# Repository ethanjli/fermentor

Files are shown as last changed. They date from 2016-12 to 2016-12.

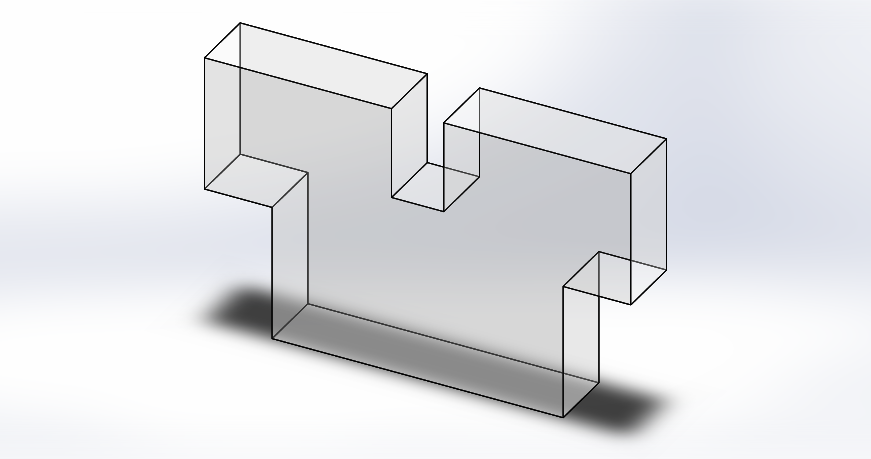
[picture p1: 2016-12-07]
design/mechanical/vessel/Temperature Sensor Mounting Plate.PNG

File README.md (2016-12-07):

# fermentor
fermentor is the codebase for a Raspberry Pi to operate a simple Arduino-driven fermentor and provide a real-time web interface for high-level control of fermentor behavior. This was done by Ethan Li and Jessica Lam for the project extension for BIOE 123 ("Optics and Devices Lab") at Stanford University. This project implements proportional temperature control of a fermentor, along with OD and green absorption sensing to monitor growth of a custom E coli strain that produces purple protein. View a writeup of the project at [ethanjli.github.io/fermentor](//ethanjli.github.io/fermentor).

## Dependencies
The following must be installed to run the web interface:
- [python 2](https://www.python.org/): required by Flask-SocketIO
- [numpy](http://www.numpy.org/): for basic data processing
- [Flask](http://flask.pocoo.org/)
- [Flask-SocketIO](https://github.com/miguelgrinberg/Flask-SocketIO) for real-time communication between a web browser and the server
- [Python-Arduino-Command-API](https://github.com/thearn/Python-Arduino-Command-API) for Arduino interfacing.

The project also uses [jQuery](http://jquery.com) for live page updating and [Google Charts](https://developers.google.com/chart/) for data plotting.

## Issues
Because this project was implemented only over a span of four days, and all of its substantive components were implemented over the course of 48 hours, this project is not good for production use:
- The plot update messages sent over WebSockets are wasteful in terms of data and processor time.
- UI design was not a high priority, given the time constraints.
- The data structures used are not the most suitable ones possible. They are not always initialized/reinitialized properly.
- The project did not undergo exhaustive testing or thorough quality checking.
- Certain routines are underdecomposed.
- Interface and naming are messy.
- Potential race conditions between multiple browser clients are not considered.
- Documentation is lacking in many areas.
- Notably, when the web interface is run on a Raspberry Pi B+ on a 2 A power suppply while powering an Arduino, it tends to brownout. In cases when CPU load is high, the code interfacing to the Arduino tends to read egregiously incorrect temperature values.

## Getting Started
When all dependencies are installed, run `fermenter.py` for basic (non-interactive) control of the fermenter. To expose the web interface, instead run `app.py` with the necessary permissions. For example, to serve the web interface on port 80, you may need to run it through `sudo`.

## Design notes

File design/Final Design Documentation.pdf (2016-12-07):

# Final Design Documentation

## Requirements

The fermentor is to grow E. coli under constant temperature conditions while monitoring the cell color change, the overall density of the cells.

The following requirements were provided by the course instructors, and system specifications were developed to meet them:

1. Sustain a fluid medium of 150 – 200 mL, without leaking
2. Maintain an internal fluid medium temperature appropriate for growing E. coli (37 deg C +/- 1 deg C)
3. Enable controlled medium sampling and material introduction without interrupting operation
4. Provide adequate aeration of fluid medium (at least 100 mL per minute of air flow)
5. Provide adequate mixing/agitation of fluid medium without shearing the cells (mixing times <10 seconds, tip speeds <2m/s)
6. Measure optical density of the fluid, robust to variable ambient lighting conditions in the lab setting (e.g., sunlight and fluorescent lights), and record the value and current time at an appropriate rate to capture expected changes in optical density (or at least once per minute)
7. Measure how green the culture color is, robust to variable ambient lighting conditions within the laboratory setting (e.g., sunlight and fluorescent lights), and record the value and current time, at an appropriate rate to capture expected changes in culture color (or at least once per minute)
8. Interface with MATLAB/computer to provide real-time plots and data logging, and record timestamp, sensor data (e.g., temperature, color, optical density), and actuator control signal data (e.g., agitation, aeration, thermal element) for display and review
9. Has a start/stop button to control system operation

Additionally, we imposed the following requirement on our project:

10. Operate, monitor, and control the fermentor using a single-board computer that is not running MATLAB, and display live-updating information and plots about the fermentor onto a webpage.

## System-Level Specifications and Verification Test Results

Some specification numbers refer to subsystem specifications, hence gaps in numbering of the system-level specifications.

Specification
number

Specification
Description
Test to perform | Relevant Requirement

Specification
[units]

Measured
Value [units]
1.1 | Water volume | Measure dimensions | 1 | > 200 [mL] | 10 cm x 10 cm x 4 cm
1.2 | Water Tightness | Perform dye tracing test when fermenter is filled with 200 mL of water, with leaked dye captured by paper towels around epoxy joints. Measure time until paper shows visible color. | 1 | > 1 hr | > 1 [week]
2.8 Fluid | Temperature Regulation | Measure amount of time during which system can maintain a fluid medium temperature between 36C and 38C | 2 | > 1 hr | > 1 [hr]
1.4 Material | Exchange | Measure the surface area available for medium sampling and material introduction while system is operating | 3 | > 4 [cm^2] | 10 x 10 [cm^2]
2.9 | Aeration | Measure the aeration of fluid medium | 4 | ≥ 0.00353 CFM | 7 [ft^3/min]
2.4 | Agitator Speed | Measure number of revolutions the impeller turns in 30 seconds at 0.15x speed in 200 mL of water | 5 | 5 to 58 [rev] | 47 [rev]
2.5 | Mixing Time | Measure amount of time required to fully mix a drop of food coloring when motor is at 0.15x speed in 200 mL of water at 9V supply | 5 | < 66 [s] | 5 [s]
3.12 Ambient light | robustness | Check difference between processed Arduino pin readings when the phototransistor is held at a constant distance and angle from a constant red LED and either the system is held under a box or not | 6,7 | ≤ ±5 | ±5
3.13 Phototransistor | Readings (Red LED) | Read pin values when phototransistor is illuminated through a light tube immersed in 2 cm of water gap by a red LED | 6,7 | > ~700 | 696
3.14 Phototransistor | Readings (Green LED) | Read pin values when phototransistor is illuminated through a light tube immersed in 2 cm of water gap by a red LED | 6,7 | > ~700 | 742

## System Block Diagram

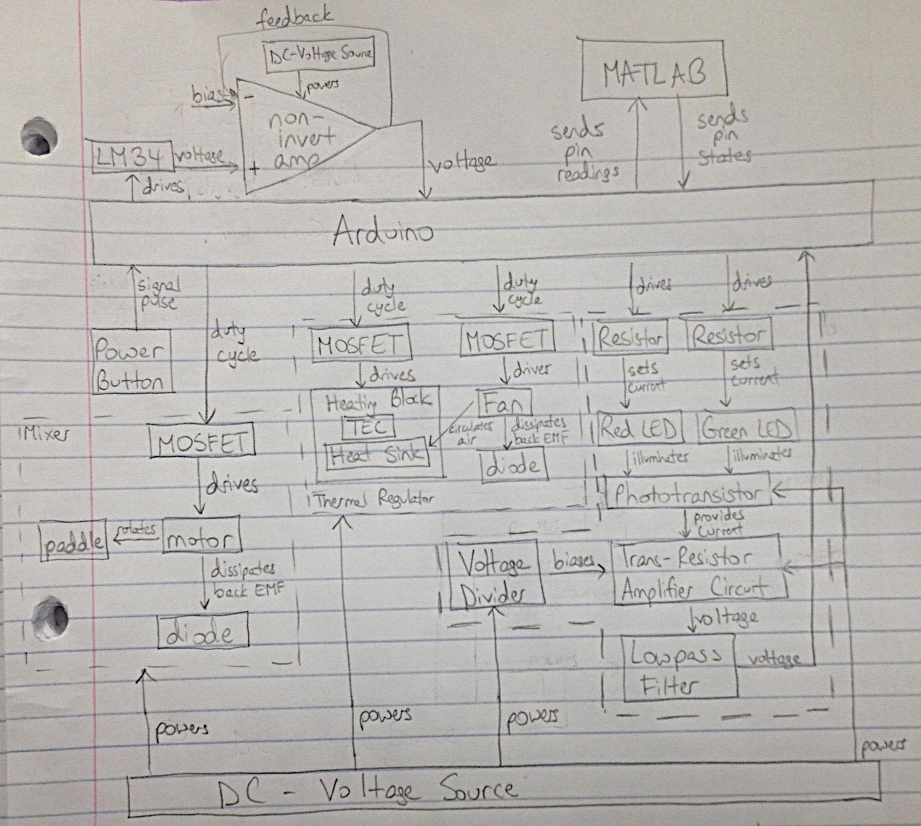
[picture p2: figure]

## Subsystem Design

### Circuit Schematics

Actuators

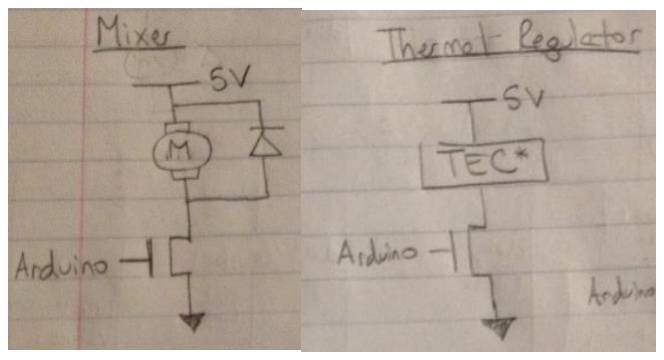
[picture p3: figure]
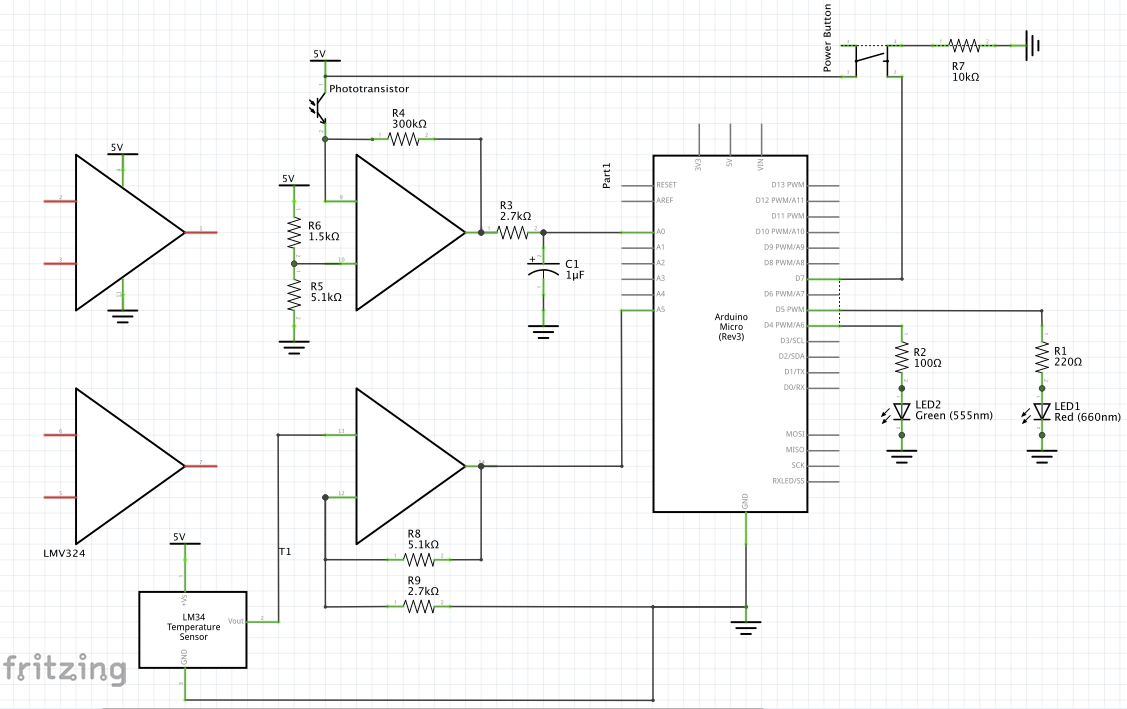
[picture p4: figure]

Sensors

### Circuit Components

- Control
- Arduino Micro
- Raspberry Pi B+
- Mixer
- IRF520 nMOS transistor
- DC Motor (PAN14EE12AA1)
- Diode IN4935
- Thermal Regulation
- IRF520 nMOS transistor
- TEC 12706 thermoelectric cooler
- Temperature Sensing
- LM34
- LMV324
- 2.7 kΩ and 5.1 kΩ resistors
- Power Button
- Tactile switch
- 10 kΩ resistor
- Optical Sensing
- Green LED
- Red LED
- 100 Ω, 220 Ω, 1.5 kΩ, 2.7 kΩ, and 5.1 kΩ resistors
- 1 μF capacitor
- LMV324
- Phototransistor
- Ventilation
- IRF520 nMOS transistor
- Fan (NB40100V2-000U-A99)
- Diode IN4935

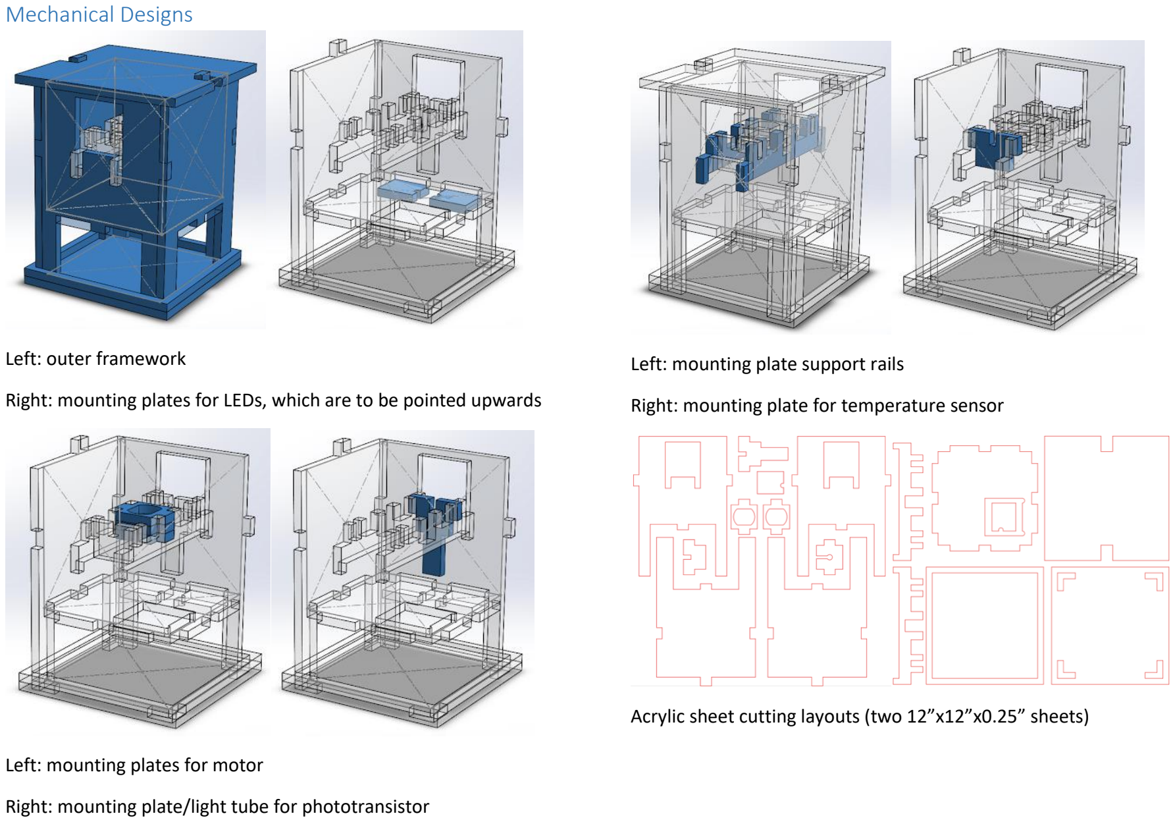
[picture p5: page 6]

### Mechanical Designs

Left: outer framework

Right: mounting plates for LEDs, which are to be pointed upwards

Left: mounting plates for motor

Right: mounting plate/light tube for phototransistor

Left: mounting plate support rails

Right: mounting plate for temperature sensor

Acrylic sheet cutting layouts (two 12”x12”x0.25” sheets)

### Build Notes

Initial breadboard layout:

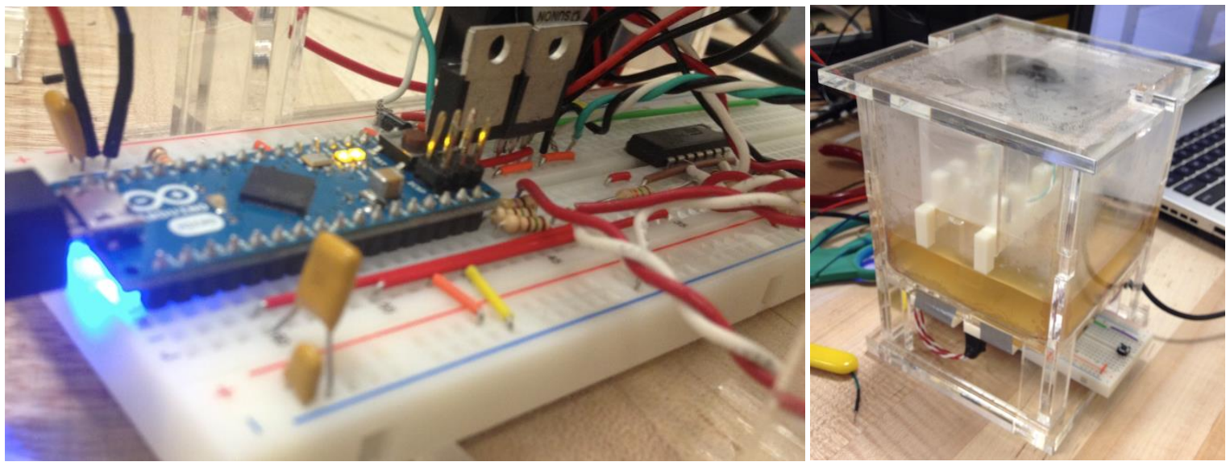
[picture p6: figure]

The twisted group of green, red, and black wire in the above image leads to a MOSFET mounted on the heatsink that is epoxied to the TEC. The heatsink cools the MOSFET, which would otherwise get extremely hot from driving the TEC.

The LED mounting plates are duct taped to the vessel.

### Breadboard layout optimization

The following is a compacted version of the breadboard layout shown on the previous page, with the MOSFET for the TEC mounted directly onto the heatsink of the TEC, rather than sitting on the breadboard:

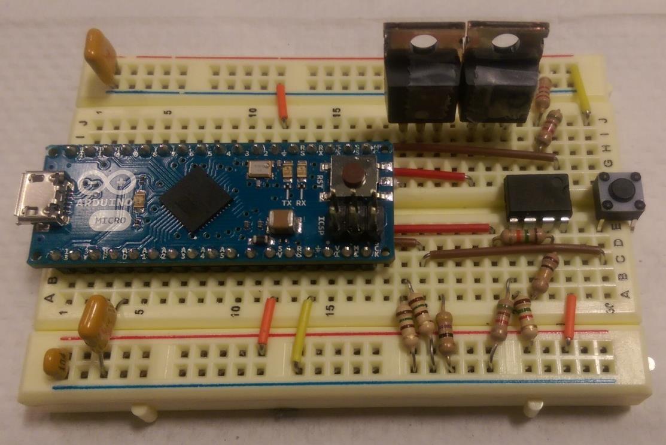
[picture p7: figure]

When all off-breadboard components are plugged in, this layout will have four free rows; all other rows will be used.

## Subsystem Specifications and Unit & Integration Test Results

Specification
number

Specification
description
Test to perform | Relevant requirement

Specification
[units]

Measured
value [units]
1.1 | Water volume | Measure dimensions | 1 | > 200 [mL] | 10 cm x 10 cm x 4 cm
1.2 | Water tightness | Perform dye tracing test, with leaked dye captured by paper towels around epoxy joints. Measure time until paper shows visible color. | 1 | > 1 [h] | > 1 [h]
1.3 Clearance | underneath vessel | Measure height of vessel base above tabletop | 2 | > 4 [cm] | 5.3 [cm]
1.4 Material | exchange | Measure cross-sectional area of an opening in the vessel that can be accessed while system is operational | 3 | > 4 [cm² ] | 10 x 10 [cm² ]
2.1 | Aerator current | Measure current through circuit when fan is running for 20 min | 1, 2 | 0.9 [μA] to 180 [mA] | ~130 [mA]
2.2 | Agitator current | Measure current through circuit when motor is running at full speed in water | 3 | > 0 [mA] | 260 [mA]
2.3 Agitator stall | current | Measure current through circuit when motor is stalled for 20 min | 4 | > 0 [mA] | ~ 250 [mA]
2.4 | Agitator speed | Measure number of revolutions the impeller turns in 30 seconds at 0.15x speed in water | 5 | 5 to 58 [rev] | 47 [rev]
2.5 | Mixing time | Measure time until water homogeneity after addition of a drop of food coloring at a vessel corner when motor is at 0.15x speed | 6 | < 66 [s] | 5 [s]
2.6 Thermal | regulator current | Measure current through circuit when heater is running at full duty cycle for 200 mL of water for 20 min with 5 V supply. | 7 | ~ 2.28 [A] | 250 [mA]
2.7 Thermal | regulator responsiveness | Measure time required to heat 200 mL of water from room temperature up to 37 °C with 9 V supply. | 8 | < 30 [min] | 23 [min]

3.1 OD | measurement rate | Measure the minimum rate at which OD measurements are taken | 1 | > 1 [min⁻¹ ] | 0.67 [s⁻¹ ]
3.2 Greenness | measurement rate | Measure the rate at which greenness measurements are taken | 2 | > 1 [min⁻¹ ] | 0.67 [min⁻¹ ]
3.3 Light | normalization measurement | Check whether measurements are normalized to ambient light | 1, 2 | Yes | Yes
3.5 60 Hz noise | attenuation | Measure gain of a 60 Hz green LED flickering superimposed on a DC red LED illumination | 1,2 | < 0.75 | ~0.5
3.6 Light dynamic | range minimum | Check unprocessed Arduino pin reading when the phototransistor is completely blocked | 1,2 | ~770-780 | 765
3.7 Ceiling light | sensitivity | Check difference between unprocessed Arduino pin readings when the phototransistor is completely blocked and when the phototransistor is pointed upwards at/under a ceiling light | 1,2 | < 100 | ~60
3.8 Downwards | ceiling light sensitivity | Check difference between unprocessed Arduino pin readings when the phototransistor is completely blocked and when the phototransistor is pointed downwards away from a ceiling light | 1,2 | <50 | 0
3.9 Red light | dynamic range maximum | Check processed Arduino pin reading when the phototransistor is illuminated by a red LED across a 2 cm air gap between the LED and the phototransistor | 1 | > 700 | 750
3.10 Green light | dynamic range maximum | Check processed Arduino pin reading when the phototransistor is illuminated by a green LED across a 2 cm air gap between the LED and the phototransistor | 2 | > 700 | 750
3.11 Measurement | consistency | Check variation across processed Arduino pin readings when the phototransistor is held at a constant distance and angle from a constant red LED | 1,2 | ≤ ±5 | ±1
3.12 Ambient light | robustness | Check difference between processed Arduino pin readings when the phototransistor is held at a constant distance and angle from a constant red LED and either the system is held under a box or not | 1,2 | ≤ ±5 | ± 5

4.1 MOSFET | reliability | Use oscilloscope to measure duty cycle of MOSFET driven by the Arduino at 50% duty cycle | 2 | 50% | 50%
4.2 Maximum fluid | temperature | Drive TEC at 100% duty cycle heating 200 mL of initially-room-temperature water and check whether fluid can be heated to 38 °C | 2 | Yes | Yes
4.3 Fluid response | time (heating) | Measure time required to heat (100% duty cycle TEC) 200 mL of stirred fluid (25% duty cycle motor) from 36 °C to 38 °C | 2 | < 20 [min] | 5 [min]
4.4 Fluid response | time (cooling) | Measure time required to cool (0% duty cycle TEC) 200 mL of stirred fluid (25% duty cycle motor) from 38 °C to 36 °C | 2 | < 20 [min] | 3 [min]
4.5 LM34 calibration | (lower) | Measure steady-state voltage of LM34 output when immersed in 26 °C fluid | 2 | ~ 0.716 [V] | 0.26 [V] (pin value 145)
4.6 LM34 calibration | (upper) | Measure steady-state voltage of LM34 output when immersed in 38 °C fluid | 2 | ~ 1 [V] | 0.38 [V] (pin value 214)
4.7 | Amplifier gain | Measure gain of amplifier circuit | 2 | ~ 2.89 | 2.85

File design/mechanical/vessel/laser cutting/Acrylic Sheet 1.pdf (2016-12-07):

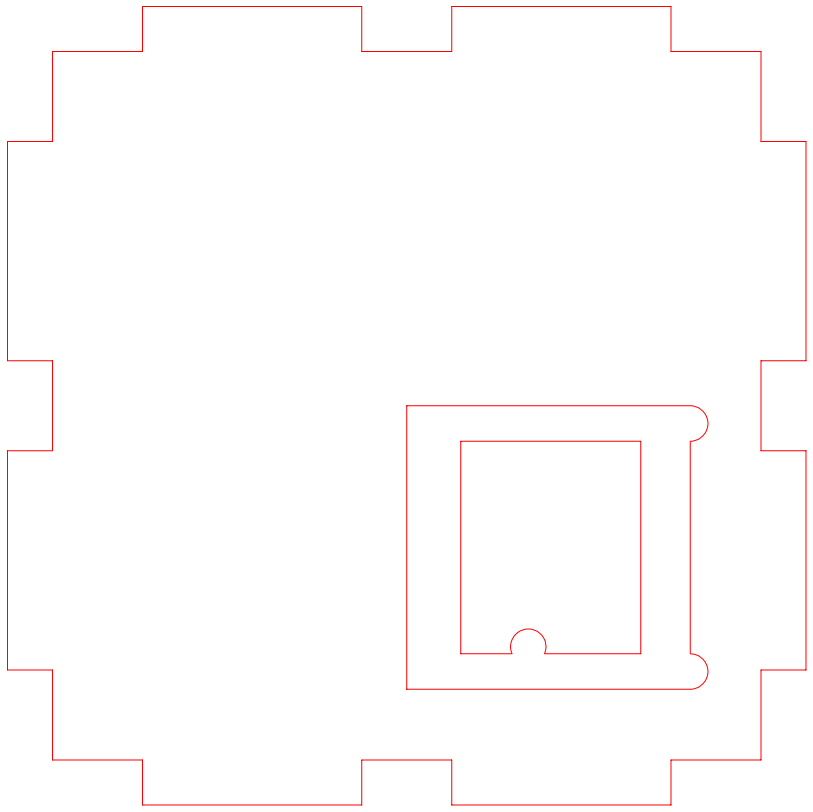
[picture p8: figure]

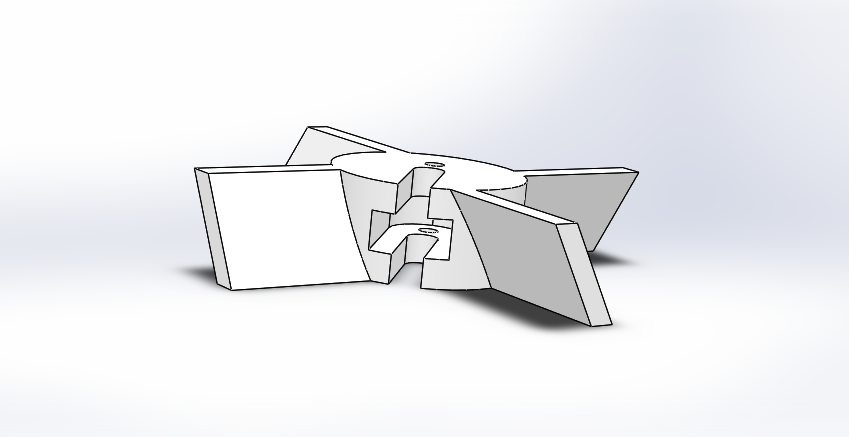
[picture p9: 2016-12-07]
design/mechanical/impeller/Impeller inner.PNG

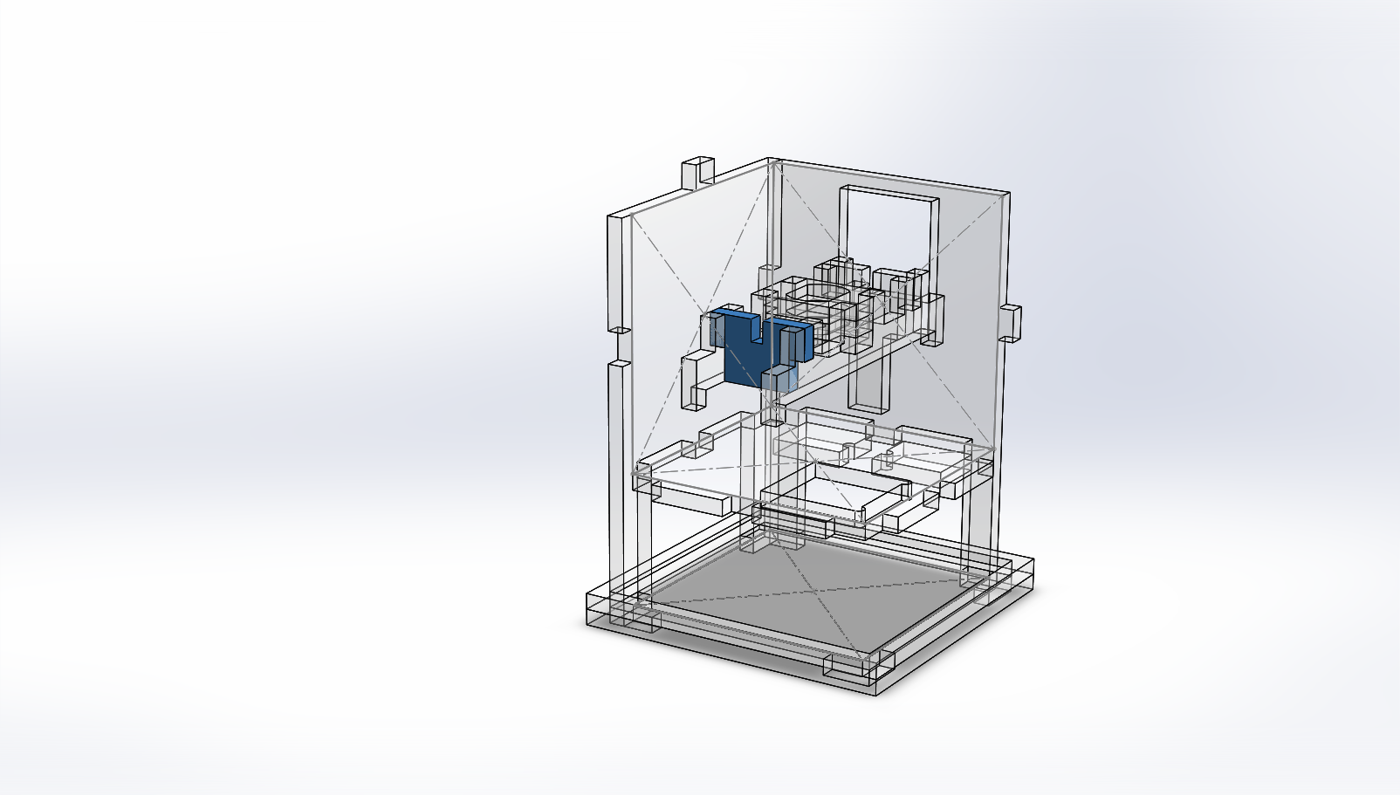
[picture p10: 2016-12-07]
design/mechanical/vessel/VesselTemperatureSensor.PNG

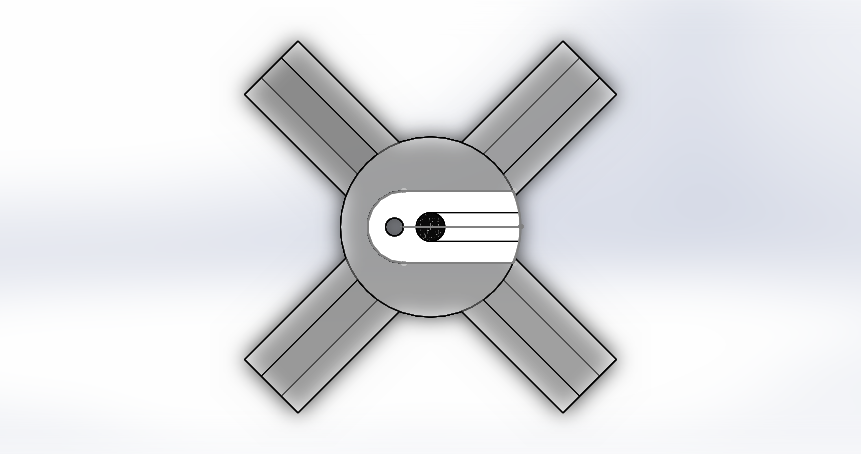
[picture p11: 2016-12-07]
design/mechanical/impeller/Combined top.PNG

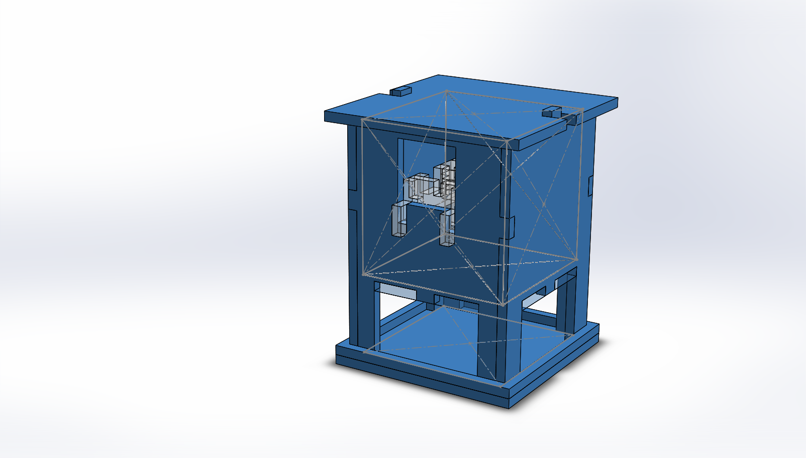
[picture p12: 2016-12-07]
design/mechanical/vessel/VesselExterior.PNG

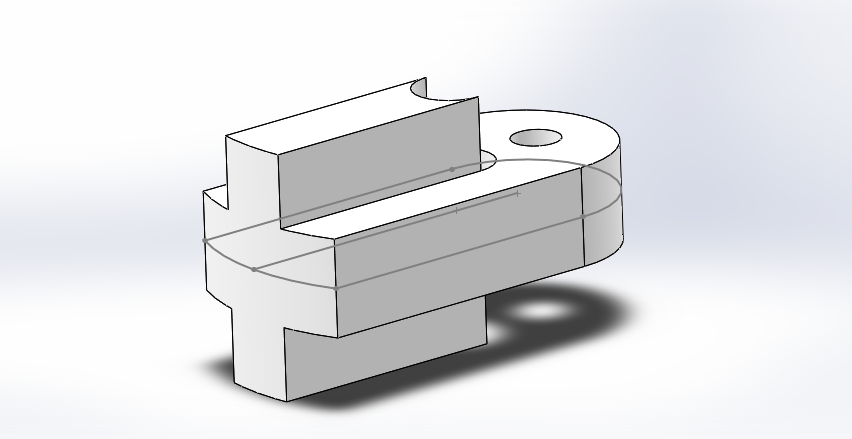
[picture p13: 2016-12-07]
design/mechanical/impeller/Inner.PNG

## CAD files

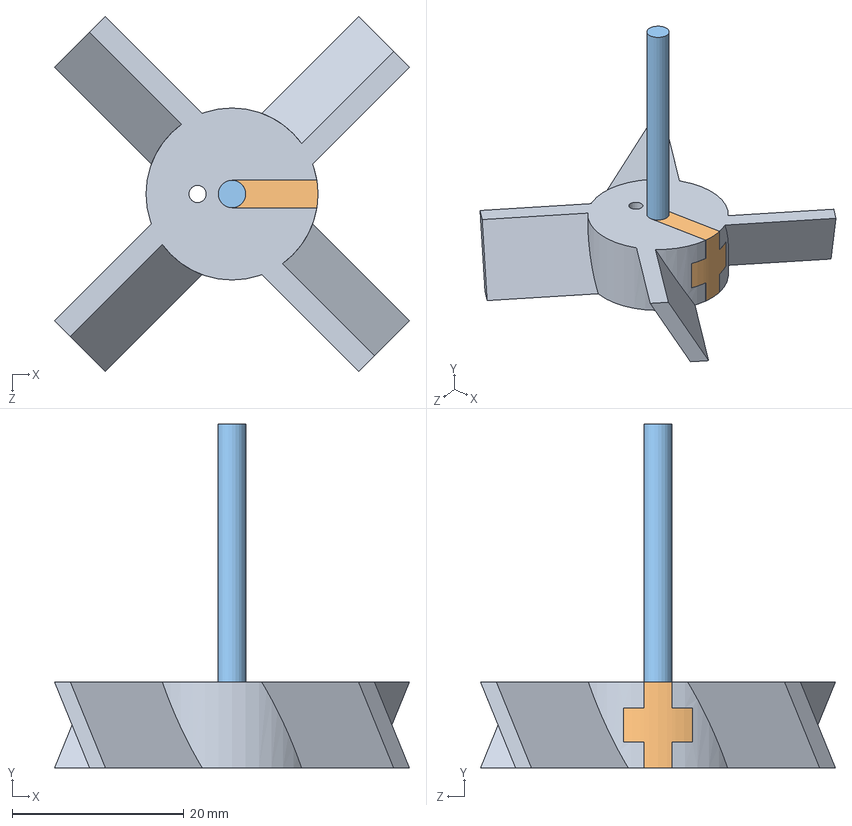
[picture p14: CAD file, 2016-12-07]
design/mechanical/impeller/Combined.SLDASM
41.3 x 40.0 x 41.3 mm
Impeller
Inner
Shaft

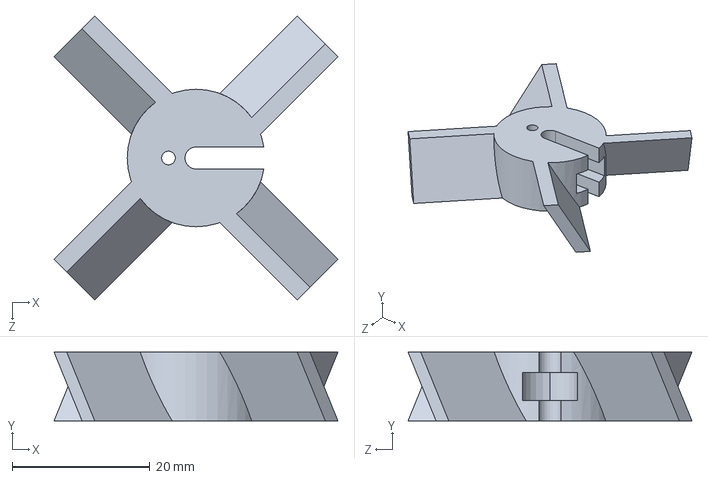
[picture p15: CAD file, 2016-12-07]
design/mechanical/impeller/Impeller.SLDPRT
41.3 x 10.0 x 41.3 mm

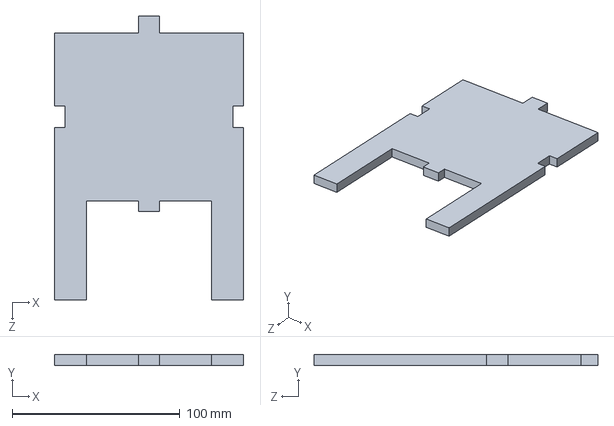
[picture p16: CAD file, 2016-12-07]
design/mechanical/vessel/LeftAndRightWithCornerLegs.SLDPRT
112.7 x 6.35 x 169.1 mm

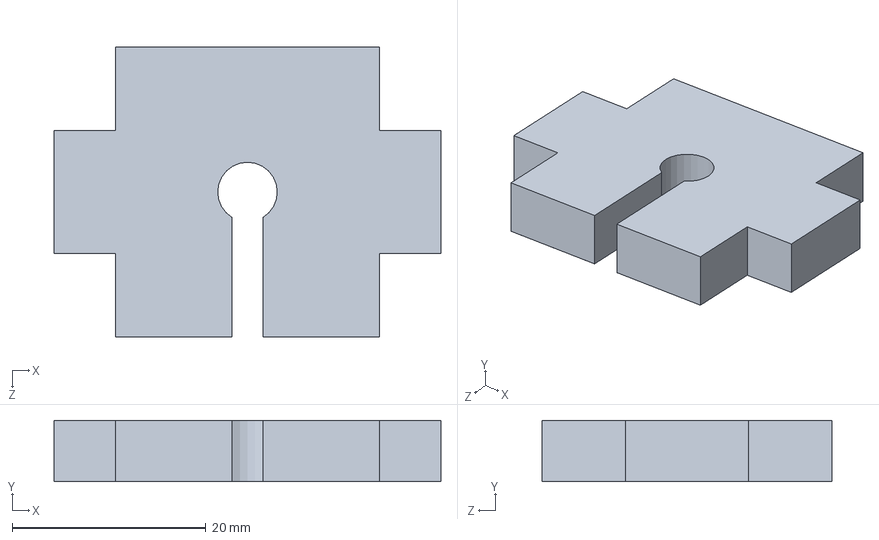
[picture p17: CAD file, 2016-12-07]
design/mechanical/vessel/Motor Base Plate.SLDPRT
40.0 x 6.35 x 30.0 mm

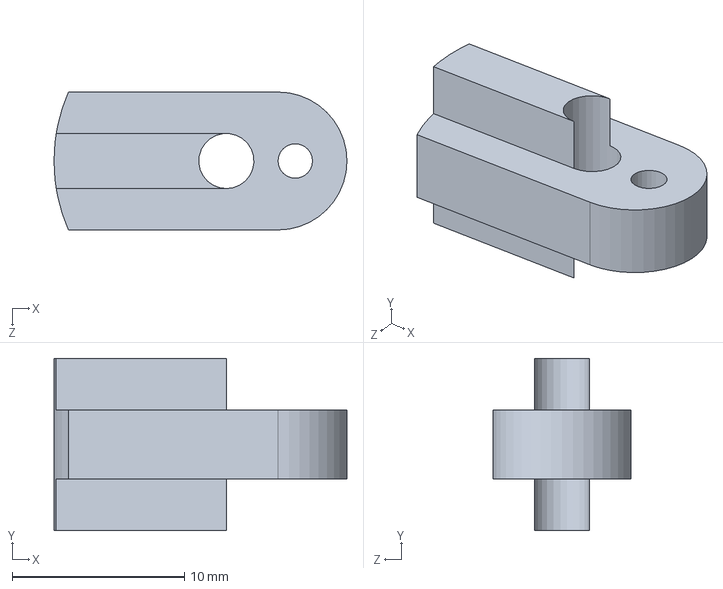
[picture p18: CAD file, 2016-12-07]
design/mechanical/impeller/Inner.SLDPRT
17.0 x 10.0 x 8.00 mm

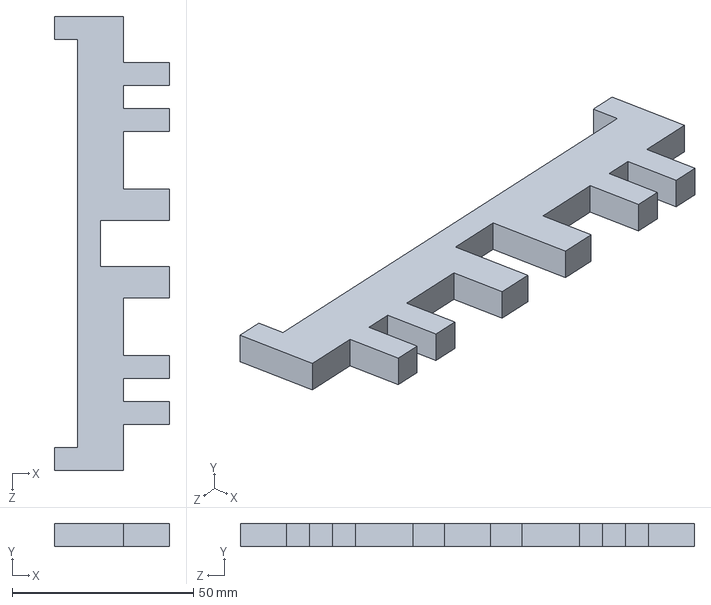
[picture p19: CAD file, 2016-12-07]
design/mechanical/vessel/PlatformSupports.SLDPRT
31.8 x 6.35 x 125.4 mm

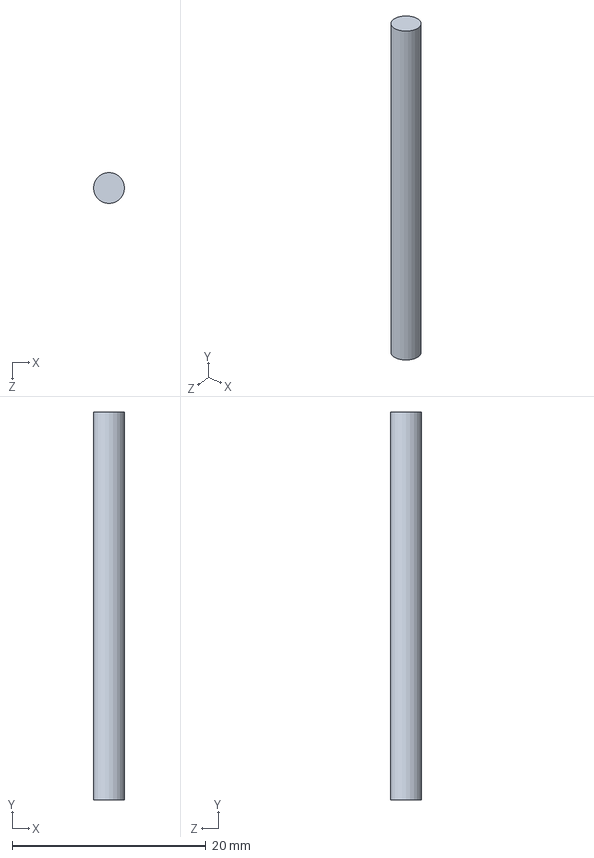
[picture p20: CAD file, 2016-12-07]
design/mechanical/impeller/Shaft.SLDPRT
3.20 x 40.0 x 3.20 mm

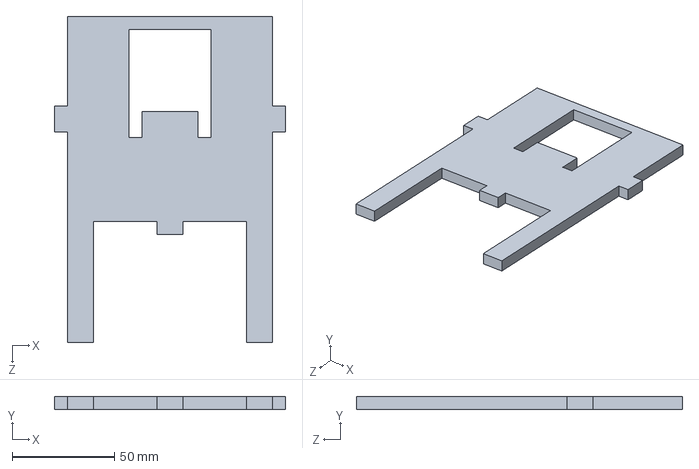
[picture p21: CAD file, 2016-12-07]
design/mechanical/vessel/FrontAndBackWithCornerLegs.SLDPRT
112.7 x 6.35 x 159.1 mm

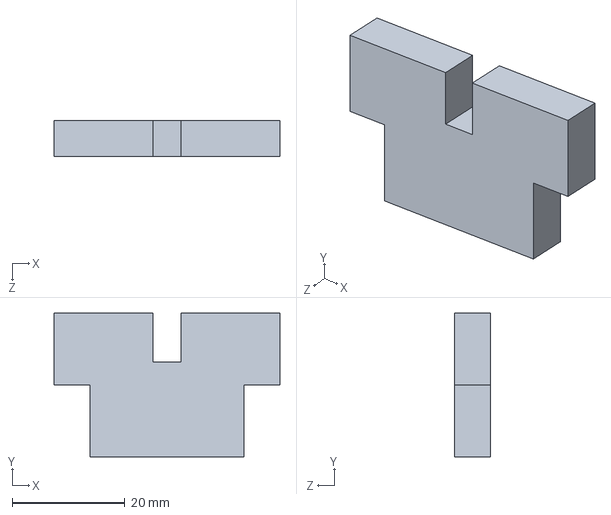
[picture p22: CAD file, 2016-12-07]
design/mechanical/vessel/Temperature Sensor Mounting Plate.SLDPRT
40.0 x 25.4 x 6.35 mm

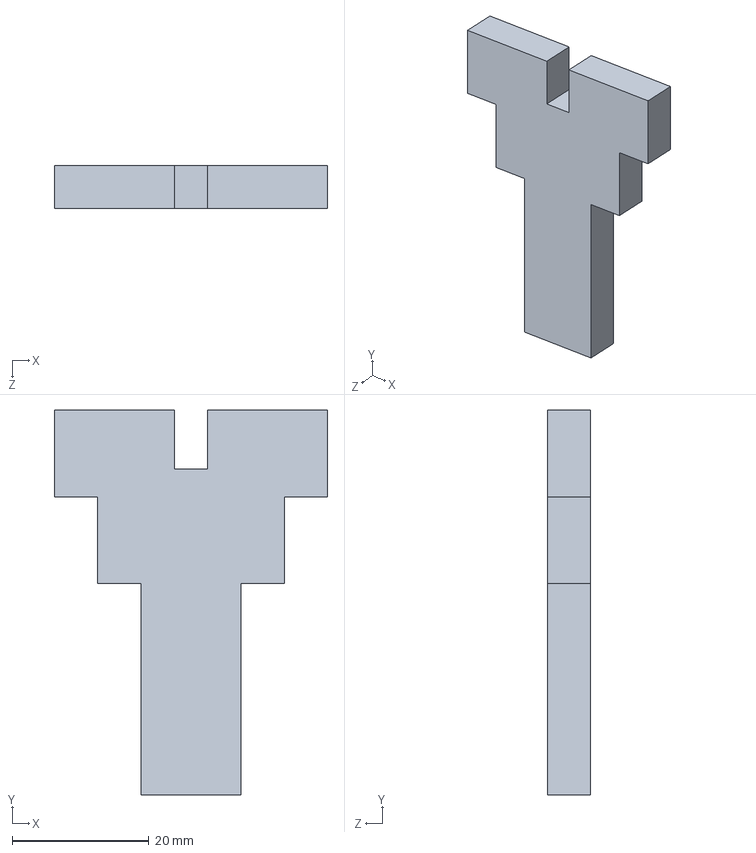
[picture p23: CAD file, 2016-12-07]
design/mechanical/vessel/Phototransistor Mounting Plate.SLDPRT
40.0 x 56.4 x 6.35 mm

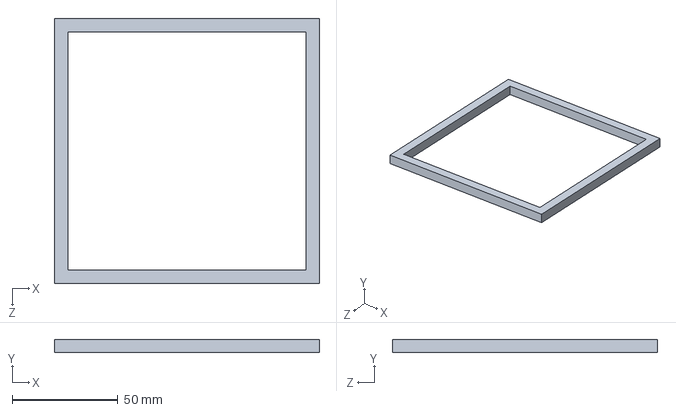
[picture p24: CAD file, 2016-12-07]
design/mechanical/vessel/FloorGuardForCornerLegs.SLDPRT
125.4 x 6.35 x 125.4 mm

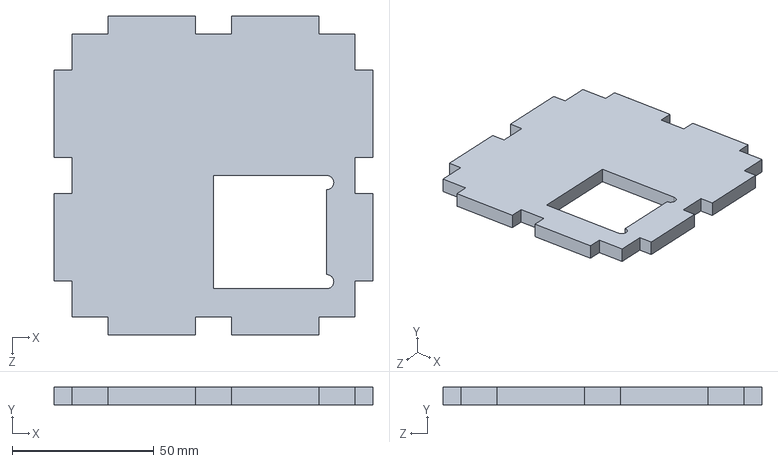
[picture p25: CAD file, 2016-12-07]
design/mechanical/vessel/BaseForCornerLegs.SLDPRT
112.7 x 6.35 x 112.7 mm

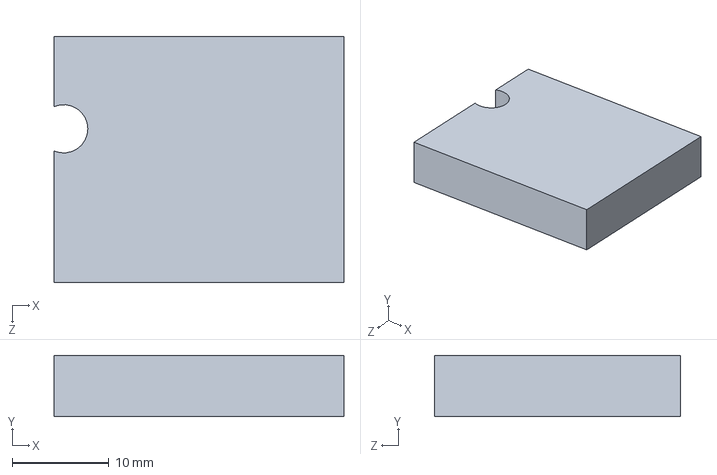
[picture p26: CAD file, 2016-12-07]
design/mechanical/vessel/LED Mounting Plate.SLDPRT
30.0 x 6.35 x 25.4 mm

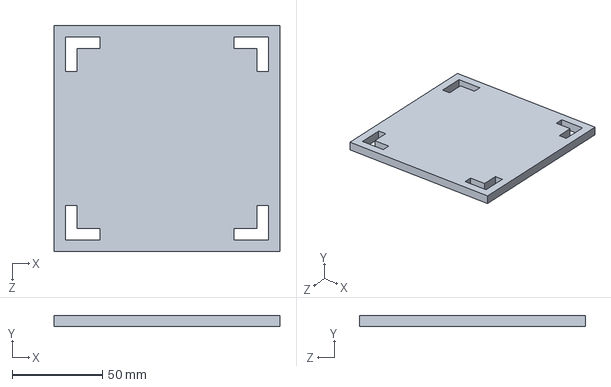
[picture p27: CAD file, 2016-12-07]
design/mechanical/vessel/FloorForCornerLegs.SLDPRT
125.4 x 6.35 x 125.4 mm

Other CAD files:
design/mechanical/vessel/Motor Alignment Plate.SLDPRT
design/mechanical/vessel/Lid.SLDPRT
design/mechanical/impeller/Impeller.STL
design/mechanical/impeller/Inner.STL
design/mechanical/vessel/LED Mounting Plate.DWG
design/mechanical/vessel/LED Mounting Plate.STL
design/mechanical/vessel/Motor Alignment Plate.DWG
design/mechanical/vessel/Motor Alignment Plate.STL
design/mechanical/vessel/Motor Base Plate.DWG
design/mechanical/vessel/Motor Base Plate.STL
design/mechanical/vessel/Phototransistor Mounting Plate.DWG
design/mechanical/vessel/Phototransistor Mounting Plate.STL
design/mechanical/vessel/PlatformSupports.DWG
design/mechanical/vessel/PlatformSupports.STL
design/mechanical/vessel/Temperature Sensor Mounting Plate.DWG
design/mechanical/vessel/Temperature Sensor Mounting Plate.STL

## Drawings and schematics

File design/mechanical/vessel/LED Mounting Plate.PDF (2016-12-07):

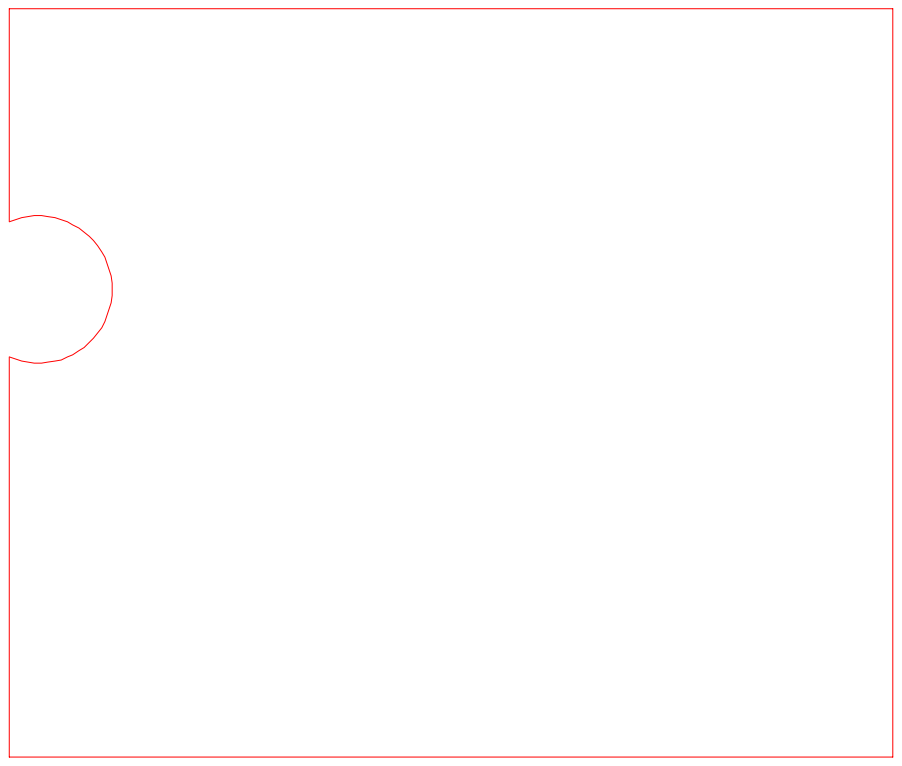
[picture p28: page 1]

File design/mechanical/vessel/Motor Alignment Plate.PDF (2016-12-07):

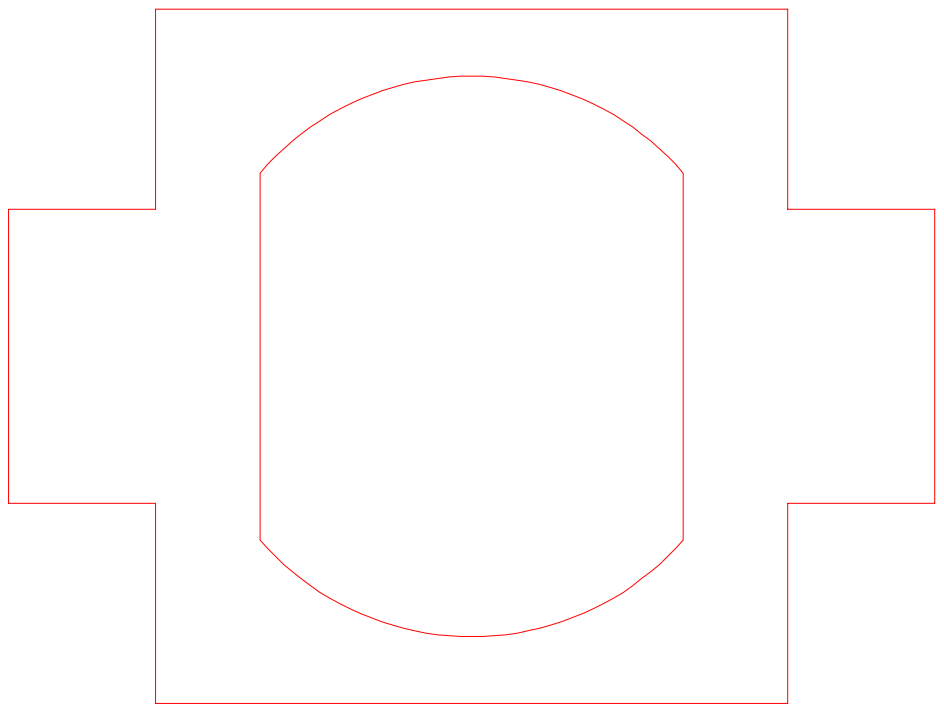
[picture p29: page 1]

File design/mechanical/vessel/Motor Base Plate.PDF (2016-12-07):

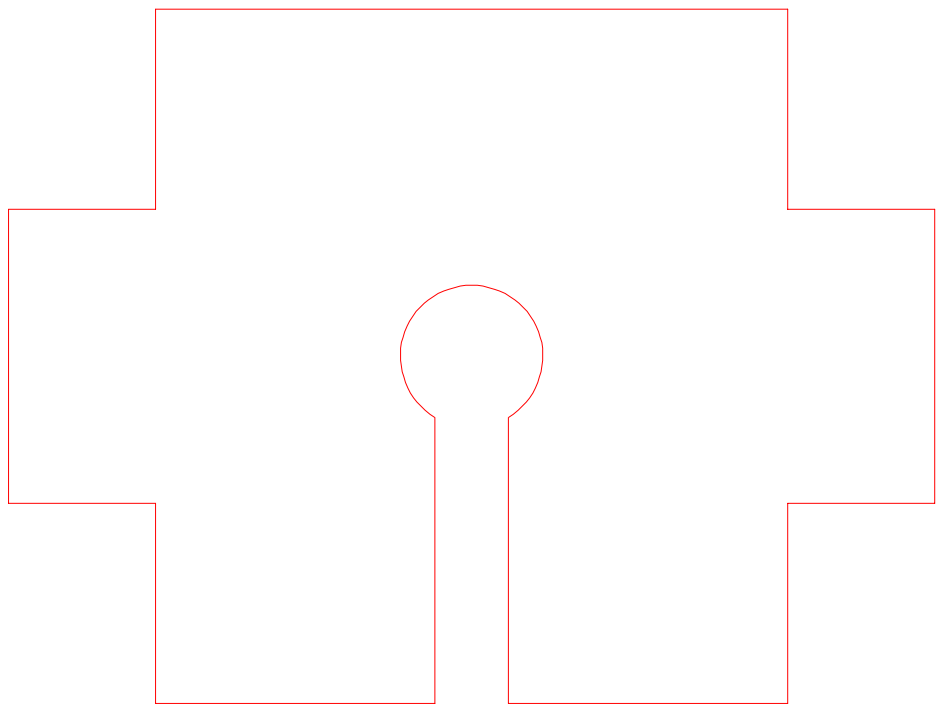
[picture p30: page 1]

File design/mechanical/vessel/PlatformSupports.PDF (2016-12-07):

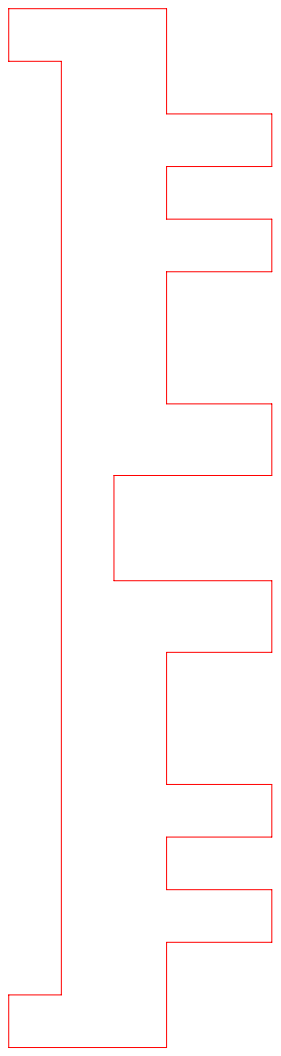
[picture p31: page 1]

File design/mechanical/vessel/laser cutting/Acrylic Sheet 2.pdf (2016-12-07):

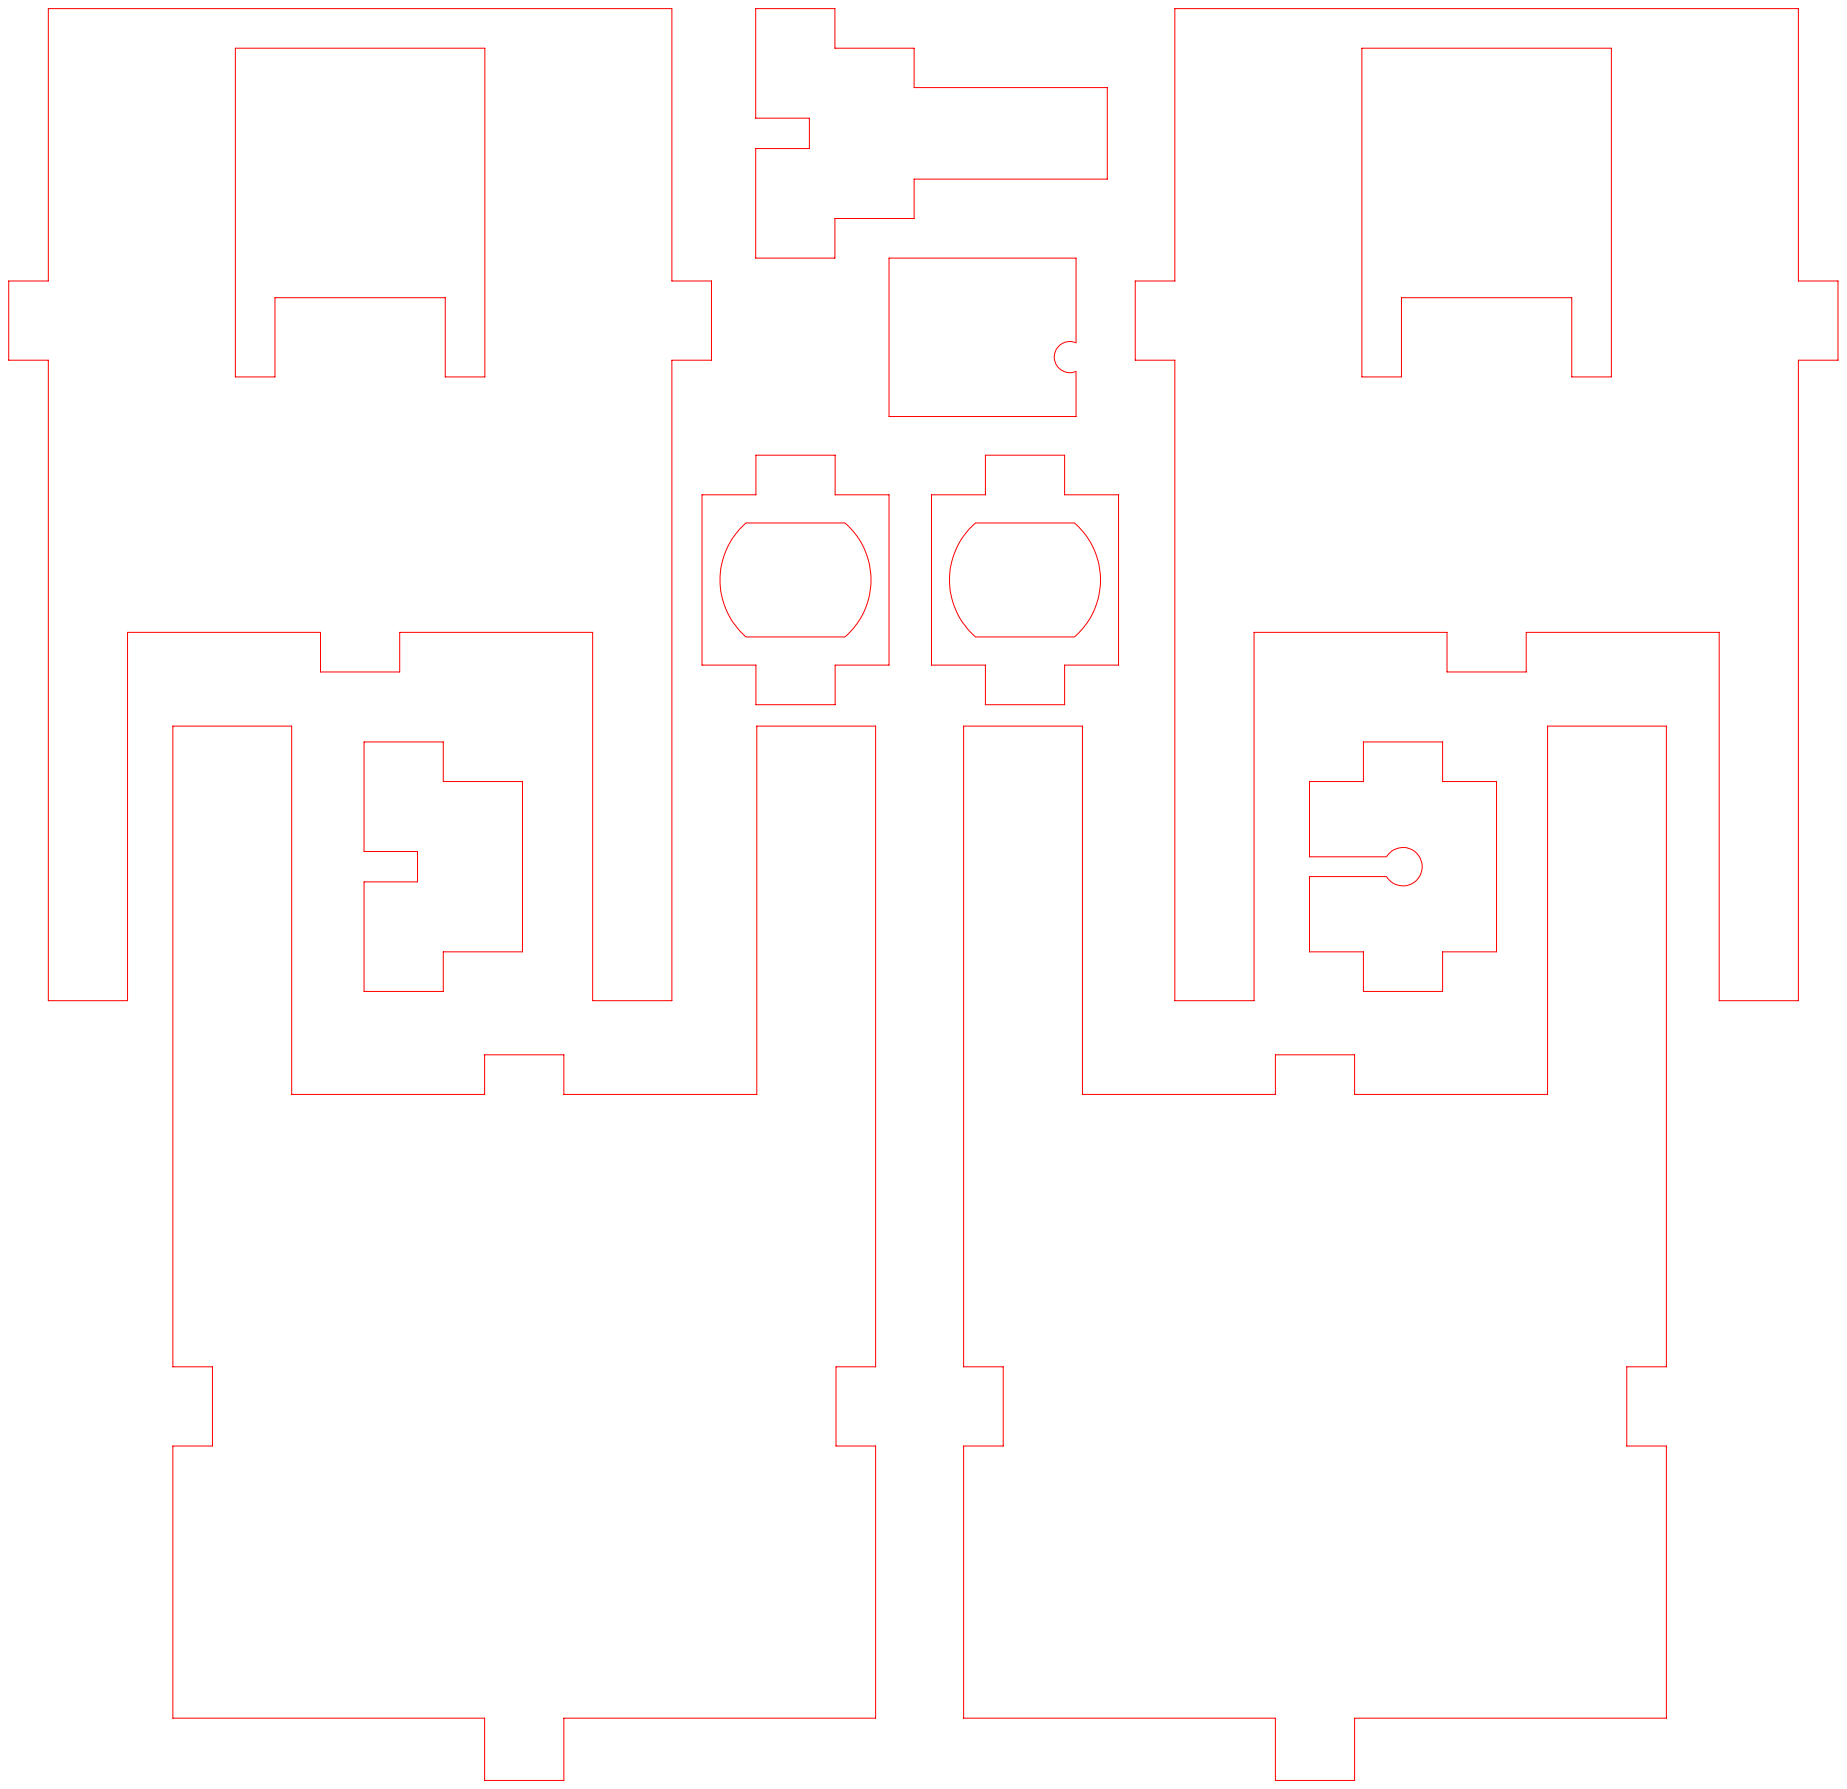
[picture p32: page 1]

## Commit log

2015-02-25 Made proof-of-concept app with live-updating system stats in Flask + jQuery for Sockets.IO.
2015-03-09 Implemented main parent function to spawn threads. Refined data recording a bit.
2015-03-09 Refined threading. Added subroutines for starting and stopping the fermenter.
2015-03-10 Ported project to use Python-Arduino-Command-API. Ported because nanpy wasn't working. Lots of bugs to be fixed, still.
2015-03-11 Added a lock for arduino communications.
2015-03-11 Found more code that should lock on the arduino
2015-03-11 Ignoring the button
2015-03-11 Fixed major bug with analog pin numbers. Totally removed the button.
2015-03-11 Trying to fix thread initialization.
2015-03-11 Switched back to a custon namespace
2015-03-12 Can't send a timedelta over socketio...
2015-03-12 Adding temperature plot
2015-03-12 Updated dashboard to include temperature plot
2015-03-12 Added current time.
2015-03-12 Trying to add buttons.
2015-03-12 Fixing button display.
2015-03-12 Added checks before deleting svg plots. Disabled the optics subsystem to debug the temperature pin.
2015-03-12 Starting to switch to google charts.
2015-03-12 Trying to add a temperature plot
2015-03-12 Using Material Line chart.
2015-03-12 Thread restarting for app.py
2016-12-07 Added mechanical design files
    [BaseForCornerLegs.SLDPRT, FloorForCornerLegs.SLDPRT, FloorGuardForCornerLegs.SLDPRT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]
2016-12-07 Added impeller parts and assembly.
    [Combined.SLDASM, Impeller.SLDPRT, Impeller.STL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]
2016-12-07 Improved mechanical design file organization
    [BaseForCornerLegs.SLDPRT, FloorForCornerLegs.SLDPRT, FloorGuardForCornerLegs.SLDPRT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]
2016-12-07 Further reorganized design files.
    [BaseForCornerLegs.SLDPRT, Combined.SLDASM, FloorForCornerLegs.SLDPRT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]
